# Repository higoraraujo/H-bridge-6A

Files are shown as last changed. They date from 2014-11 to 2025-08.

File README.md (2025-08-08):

# 6A H-Bridge Motor Control with Arduino

This project demonstrates how to control a DC motor using a 6A H-bridge and an Arduino, allowing direction reversal and speed control through PWM.

## Requirements
- Arduino (Uno, Nano or similar)
- 6A H-bridge driver
- Compatible DC motor
- Power supply suitable for the motor
- Jumper wires and prototyping components

## Connections

| Component | Arduino Pin | Description |
|---|---|---|
| IN1 | 8 | Direction input 1 |
| IN2 | 9 | Direction input 2 |
| ENA (PWM) | 10 | Motor enable / Speed control |
| Vcc | 5V | Logic supply |
| GND | GND | Ground reference |

Motor power must be connected directly to the H-bridge, respecting the motor's current rating.

## Usage
1. Connect the components according to the table above.
2. Upload `Code/HBridgeControl.ino` to your Arduino.
3. (Optional) Open the Serial Monitor for debugging.
4. The motor will alternate between forward and reverse rotations with programmed pauses.

### Advanced control

For more flexibility, try `Code/Code.ino`. This sketch configures Timer1 for a
20 kHz PWM frequency and exposes helper functions to:

- Smoothly ramp speed in either direction
- Change PWM frequency at runtime
- Drive the motor using only two hardware PWM pins (OC1A/OC1B)

Use this version when you need finer control over switching frequency or wish
to experiment with acceleration profiles.

## Safety
- Use appropriate fuses to protect against short circuits.
- Avoid touching the H-bridge or motor while powered.
- Ensure the power supply can handle the motor's current draw.

## Flowchart
```mermaid
flowchart TD
    A[Start] --> B[Configure pins]
    B --> C[Spin forward]
    C --> D[Delay 3s]
    D --> E[Stop motor]
    E --> F[Delay 1s]
    F --> G[Spin backward]
    G --> H[Delay 3s]
    H --> I[Stop motor]
    I --> J[Delay 1s]
    J --> C
```

## License
This project is licensed under the MIT License.

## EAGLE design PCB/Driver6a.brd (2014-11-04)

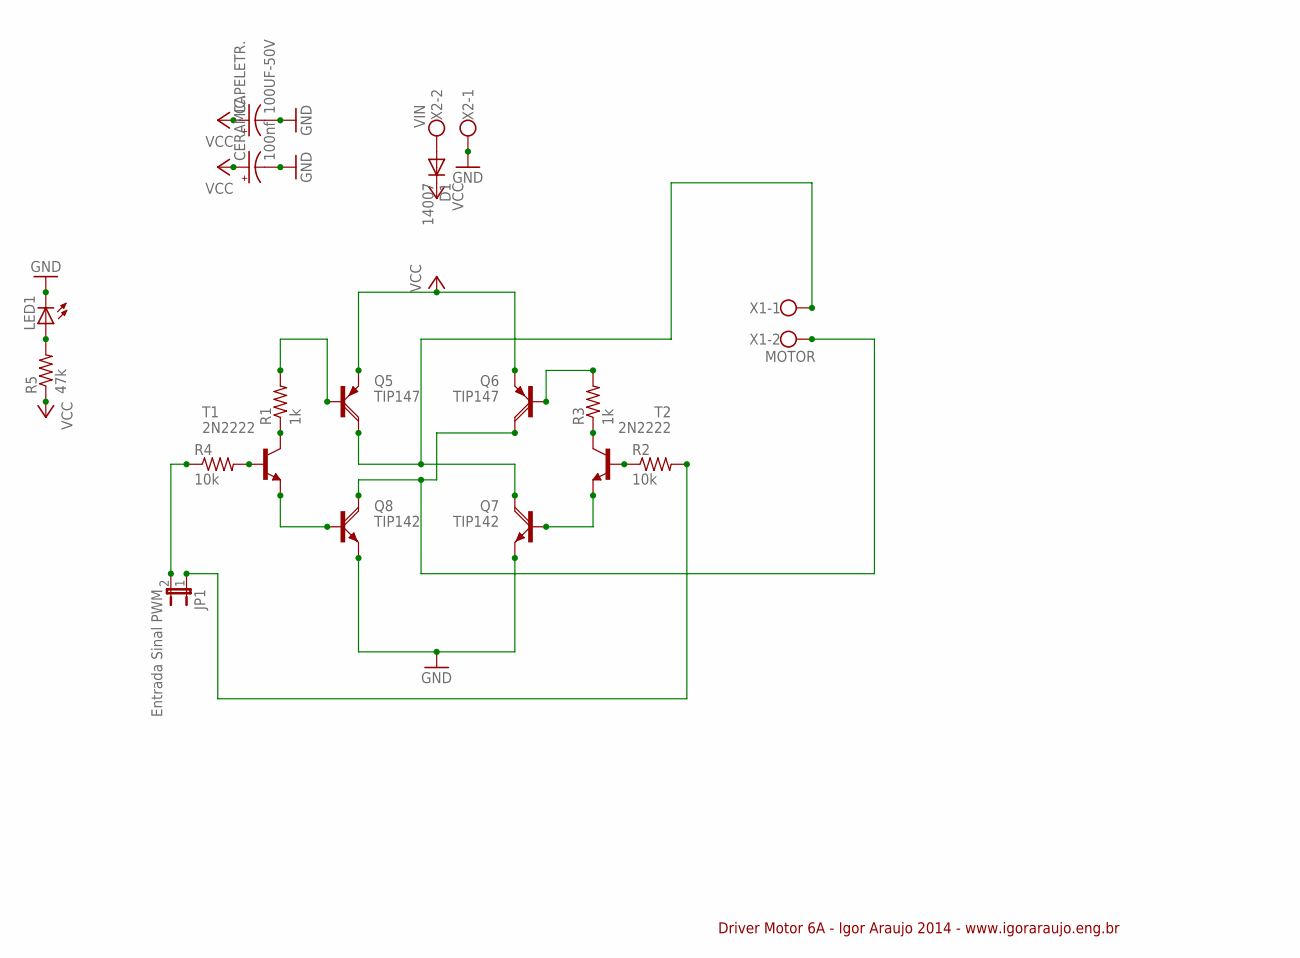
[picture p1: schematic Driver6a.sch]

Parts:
CAPELETR.: 100UF-50V; E3,5-8
CERAMIC.: 100nf; E3,5-8
D1: 14007; DO35-7
JP1: Entrada Sinal PWM; JP1
LED1: LED3MM
Q5, Q6: TIP147; TO220AH
Q7, Q8: TIP142; TO220AH
R1, R3: 1k; 0207/10
R2, R4: 10k; 0207/10
R5: 47k; 0207/10
T1, T2: 2N2222; TO18
X1: MOTOR; W237-132
X2: VIN; W237-132

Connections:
GND: CAPELETR..-, CERAMIC..-, LED1.K (C), Q7.E, Q8.E, X2.1
unnamed: Q5.C, Q7.C, X1.1
unnamed: Q6.C, Q8.C, X1.2
unnamed: R1.1, T1.3 (C)
unnamed: Q5.B, R1.2
unnamed: Q8.B, T1.1 (E)
unnamed: R3.1, T2.3 (C)
unnamed: Q6.B, R3.2
unnamed: Q7.B, T2.1 (E)
unnamed: R2.1, T2.2 (B)
unnamed: R4.2, T1.2 (B)
unnamed: JP1.2, R4.1
unnamed: JP1.1, R2.2
unnamed: LED1.A, R5.2
unnamed: D1.A, X2.2
VCC: CAPELETR..+, CERAMIC..+, D1.C, Q5.E, Q6.E, R5.1

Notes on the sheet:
Driver Motor 6A - Igor Araujo 2014 - www.igoraraujo.eng.br

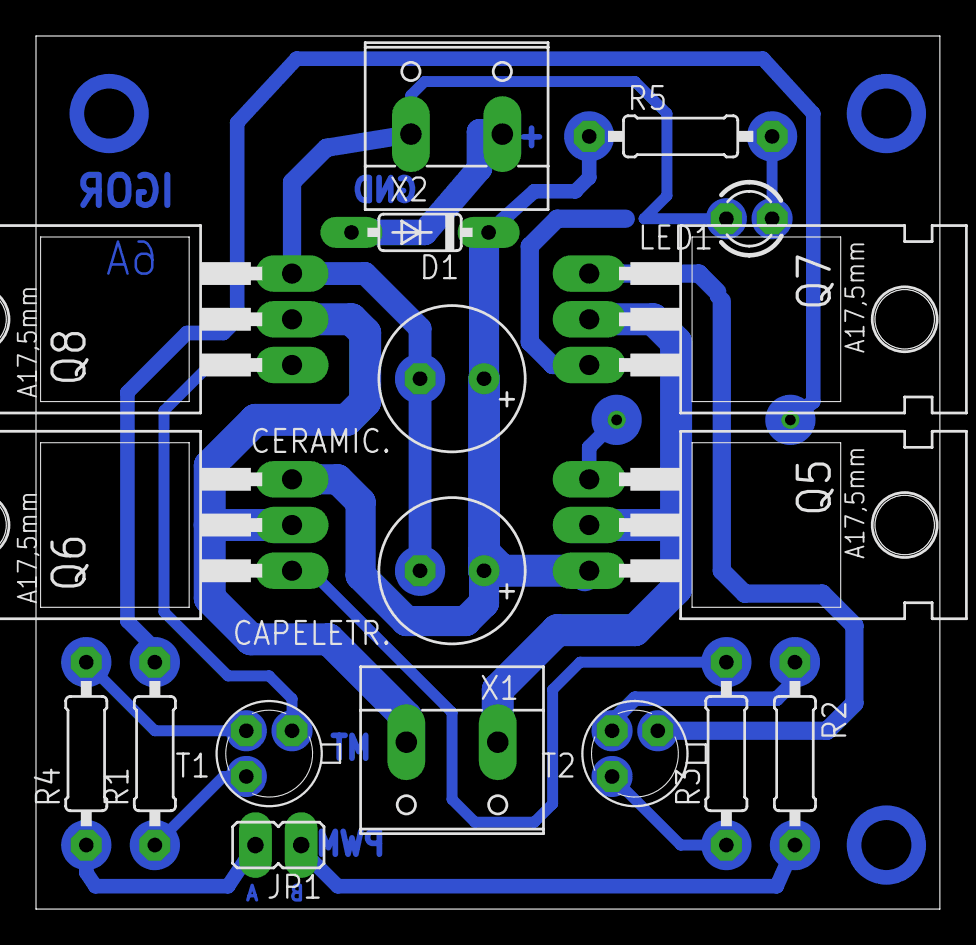
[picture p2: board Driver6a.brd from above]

Board: 2 copper layers, 50.2 x 48.5 mm, 18 parts (0 on the bottom side), 16 nets.

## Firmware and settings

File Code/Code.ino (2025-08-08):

/*
 * Advanced DC Motor control with 6A H-bridge
 * - Flexible PWM frequency via Timer1
 * - Ramp support for smooth acceleration
 * - Direction control using only two PWM channels
 *
 * Pins are configurable and must be PWM-capable.
 */

#include <Arduino.h>

const uint8_t PIN_INA = 9;   // OC1A
const uint8_t PIN_INB = 10;  // OC1B
const uint16_t DEFAULT_PWM_FREQUENCY = 20000; // 20 kHz

int currentSpeed = 0;        // -100 to 100
uint16_t pwmTop = 0;         // Timer1 TOP value

void setup() {
  setupPWM(DEFAULT_PWM_FREQUENCY);
  brake();
}

void loop() {
  // Example usage: ramp forward, then reverse
  rampTo(100, 5, 20);   // to 100% speed
  delay(1000);
  rampTo(-100, 5, 20);  // to -100% speed
  delay(1000);
}

// Configure Timer1 for Fast PWM with configurable frequency
void setupPWM(uint16_t freq) {
  pinMode(PIN_INA, OUTPUT);
  pinMode(PIN_INB, OUTPUT);

  // Reset Timer1 configuration
  TCCR1A = 0;
  TCCR1B = 0;

  // Fast PWM, TOP=ICR1, non-inverted on A/B
  TCCR1A |= _BV(COM1A1) | _BV(COM1B1) | _BV(WGM11);
  TCCR1B |= _BV(WGM13) | _BV(WGM12) | _BV(CS10); // no prescaler

  setPWMFrequency(freq);
}

// Change PWM frequency at runtime
void setPWMFrequency(uint16_t freq) {
  pwmTop = F_CPU / freq - 1;
  ICR1 = pwmTop;
  applyPWM(currentSpeed); // keep current duty
}

// Apply PWM value according to desired speed (-100..100)
void applyPWM(int speed) {
  speed = constrain(speed, -100, 100);
  uint16_t duty = (uint32_t)abs(speed) * pwmTop / 100;

  if (speed >= 0) {
    OCR1A = duty;
    OCR1B = 0;
  } else {
    OCR1A = 0;
    OCR1B = duty;
  }
  currentSpeed = speed;
}

// Smoothly ramp to target speed
void rampTo(int target, int step, uint16_t delayMs) {
  target = constrain(target, -100, 100);
  while (currentSpeed != target) {
    int next = currentSpeed < target
                ? min(currentSpeed + step, target)
                : max(currentSpeed - step, target);
    applyPWM(next);
    delay(delayMs);
  }
}

// Coast / brake the motor
void brake() {
  OCR1A = 0;
  OCR1B = 0;
  digitalWrite(PIN_INA, LOW);
  digitalWrite(PIN_INB, LOW);
  currentSpeed = 0;
}

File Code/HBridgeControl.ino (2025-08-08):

/*
 * H-Bridge 6A Motor Control
 * Author: Example Author
 * Date: 2024-07-XX
 *
 * Description:
 *  - Controls direction and speed of a DC motor
 *  - Uses PWM on enable pin and digital pins for direction
 *  - Prevents simultaneous reversal of polarity
 */

#define PIN_IN1 8  // Direction input 1
#define PIN_IN2 9  // Direction input 2
#define PIN_ENA 10 // PWM pin for speed control

void setup() {
  pinMode(PIN_IN1, OUTPUT);
  pinMode(PIN_IN2, OUTPUT);
  pinMode(PIN_ENA, OUTPUT);

  // Motor stopped initially
  digitalWrite(PIN_IN1, LOW);
  digitalWrite(PIN_IN2, LOW);
  analogWrite(PIN_ENA, 0);
}

void loop() {
  // Spin forward
  digitalWrite(PIN_IN1, HIGH);
  digitalWrite(PIN_IN2, LOW);
  analogWrite(PIN_ENA, 150); // ~60% speed

  delay(3000);

  // Stop the motor
  analogWrite(PIN_ENA, 0);
  delay(1000);

  // Spin backward
  digitalWrite(PIN_IN1, LOW);
  digitalWrite(PIN_IN2, HIGH);
  analogWrite(PIN_ENA, 150);

  delay(3000);

  // Stop again
  analogWrite(PIN_ENA, 0);
  delay(1000);
}

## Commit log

2014-11-04 H-bridge - 6A
    Code - Controling one motor DC + H-bridge 6A + Arduino - by Igor
    Araujo 2014
    2x pins PWM for control.
    [Driver6a.brd, Driver6a.sch]
2025-08-08 Constrain motor speed to valid PWM range
2025-08-08 Add English motor control example and documentation
2025-08-08 feat: add timer-based motor control with configurable pwm
